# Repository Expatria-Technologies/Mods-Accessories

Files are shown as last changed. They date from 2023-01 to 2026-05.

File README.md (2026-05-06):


### Canadian-designed open source hardware. For everyone.

# Mods & Accessories
Here you will find 3D printed enclosures, mounts, buttons, and community submitted mods for the Expatria hardware.

## Submitting Mods
When submitting a PR for a mod, please update the table in the relevant section with the following:
- Your desired creator name
- A mod title & link to your sub-folder
- A description of what you have created
- Compatibility with the various Expatria hardware, if the table within the section includes space for this. Use `:heavy_check_mark:` for :heavy_check_mark:, `:x:` for :x: and `:grey_question:` for :grey_question:

Within the sub-folder for your mod, please include a brief README with any details you think are essential or helpful for use or assembly. 

## Jog2K

| Creator | Mod Title | Description | 
| --- | --- | --- |
| Expatria | [Jog2k Deluxe](./Expatria/Jog2K_Deluxe) | Jog2K Deluxe Enclosure |
| Expatria | [Jog2k Base](./Expatria/Jog2K_Base) | Jog2K Base Enclosure |
| Logan | [FDM Buttons](./Community_Submissions/FDM_Buttons) | FDM Buttons for Jog2K Deluxe Enclosure |
| RR |  [High-Vis Buttons](./Community_Submissions/Simplified_High_Vis_Buttons) | Simplified High Vis Buttons for Jog2K Deluxe Enclosure |

## Flexi-HAL

| Creator | Mod Title | Description | 
| --- | --- | --- |
| Expatria | [Flexi-HAL DIN Mount](./Expatria/Flexi-HAL_DIN_Mount) | Flexi-HAL DIN Mount |
| TAKUYA | [Flexi-HAL + PI DIN Mount](./Community_Submissions/FLEXI_HAL_PI_DIN_RAIL_MOUNT) | Flexi-HAL + PI DIN Mount |

## HAL2K

| Creator | Mod Title | Description |  HAL2K EST | HAL2K OG|
| --- | --- | --- | --- | --- |
| Logan | [GH2K PCB Mounting Plate](./Community_Submissions/GH2K_PCB_Mounting_Plate) | Mounting Plate for HAL2K | :heavy_check_mark: | :heavy_check_mark: |

## PicoBOB

| Creator | Mod Title | Description | 
| --- | --- | --- |
| miniwini | [PicoBOB Case](./Community_Submissions/PicoBOB_Case) | Case for PicoBOB |

## Limit Breakout

| Creator | Mod Title | Description | 
| --- | --- | --- |
| Expatria | [Limit PCB Case](./Expatria/Limit_PCB_Case) | Limit Breakout Case |
| miniwini | [Limit_PCB_Enclosure](./Community_Submissions/Limit_PCB_Enclosure) | Enclosure for Limit Switch PCB |

## Switch Breakout

| Creator | Mod Title | Description | 
| --- | --- | --- |
| Logan | [Button PCB Case](./Community_Submissions/Button_PCB_Case) | Button PCB Case |

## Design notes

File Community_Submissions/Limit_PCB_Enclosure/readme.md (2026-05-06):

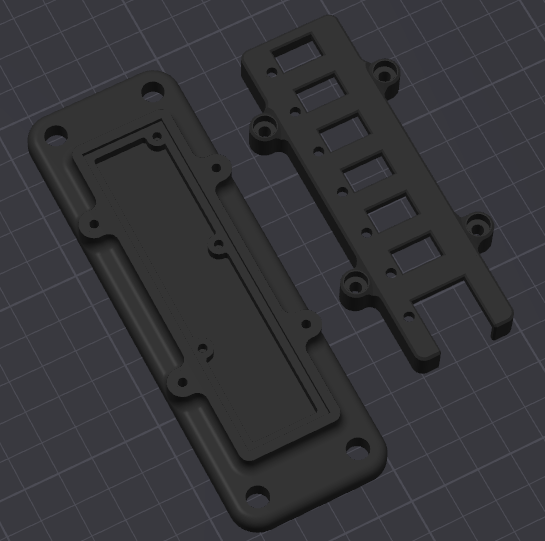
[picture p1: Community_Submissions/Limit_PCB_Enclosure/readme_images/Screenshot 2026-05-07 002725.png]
Screenshot of modified Expatria Limit PCB enclosure front view
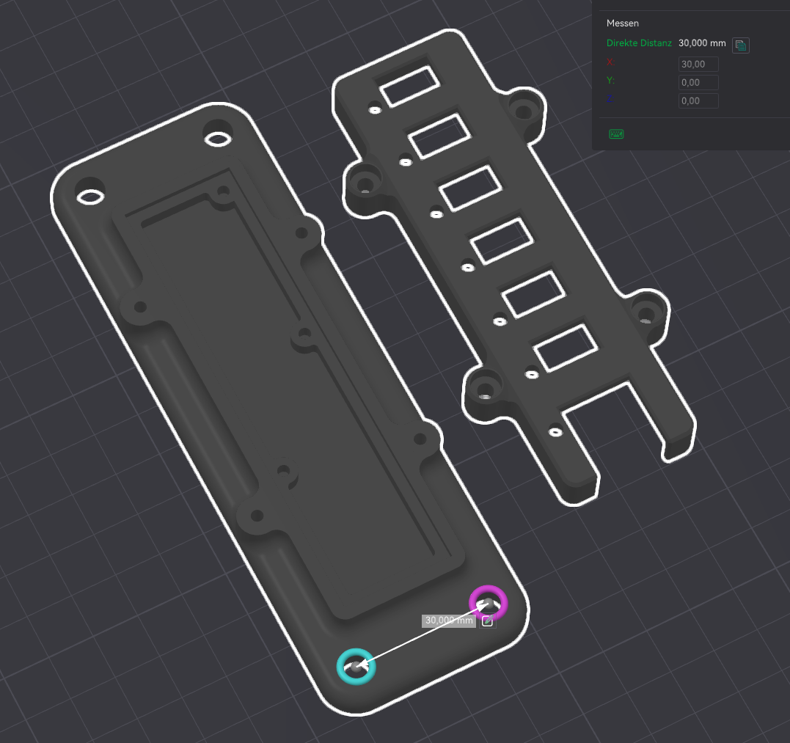
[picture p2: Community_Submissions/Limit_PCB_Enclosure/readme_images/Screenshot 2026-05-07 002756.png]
Screenshot of modified Expatria Limit PCB enclosure rear mounting holes
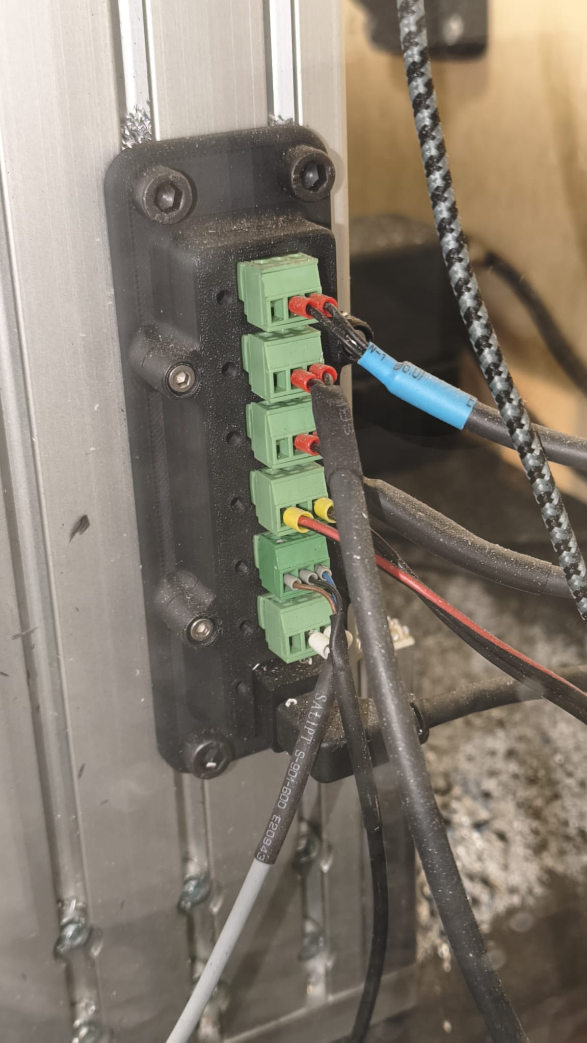
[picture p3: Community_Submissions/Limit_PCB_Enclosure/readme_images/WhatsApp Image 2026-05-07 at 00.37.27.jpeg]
Mounted Expatria Limit PCB enclosure on aluminium extrusion profile
<h2>Expatria Limit PCB Enclosure  </a>  – 60 mm Extrusion Mount</h2><p>  A modified version of the <strong><a href="https://github.com/mintracer/Mods-Accessories/tree/main/Expatria/Limit_PCB_Case" target="_blank">    Expatria Limit PCB Enclosure  </a></strong>,  adapted for mounting directly to a <strong>60 mm aluminium extrusion profile</strong>.</p><ul>  <li>Designed for 60 mm extrusion profiles</li>  <li>30 mm slot distance</li>  <li>Mounting holes sized for M6 screws</li>  <li>Clean and secure PCB enclosure mounting</li></ul><br><br><br><br><br>

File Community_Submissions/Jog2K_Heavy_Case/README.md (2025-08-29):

# Jog2k Heavy Industry Case

This is a case for the Jog2k with large, ergonomic grips and provisions for use of a longer cable.

**Warning**: This mod requires soldering custom cables, and possibly modifying SMT components on the Jog2k PCBs. As always, you are responsible for wiring things correctly to avoid possible damage to your hardware!

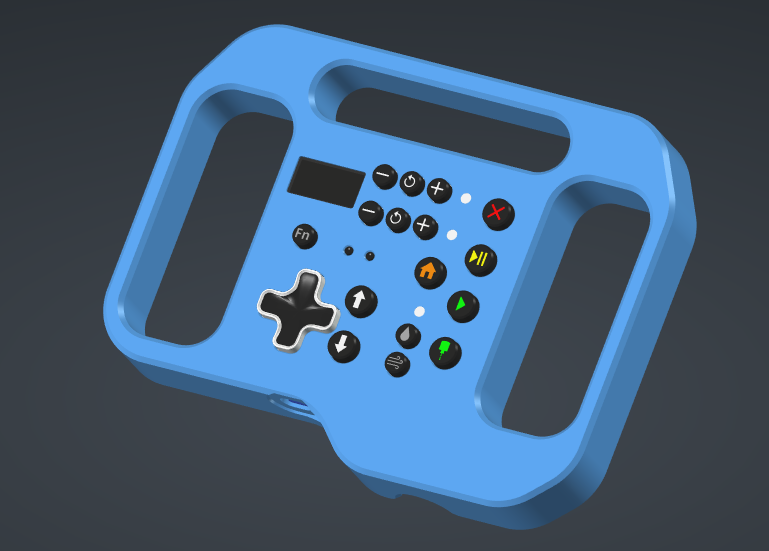
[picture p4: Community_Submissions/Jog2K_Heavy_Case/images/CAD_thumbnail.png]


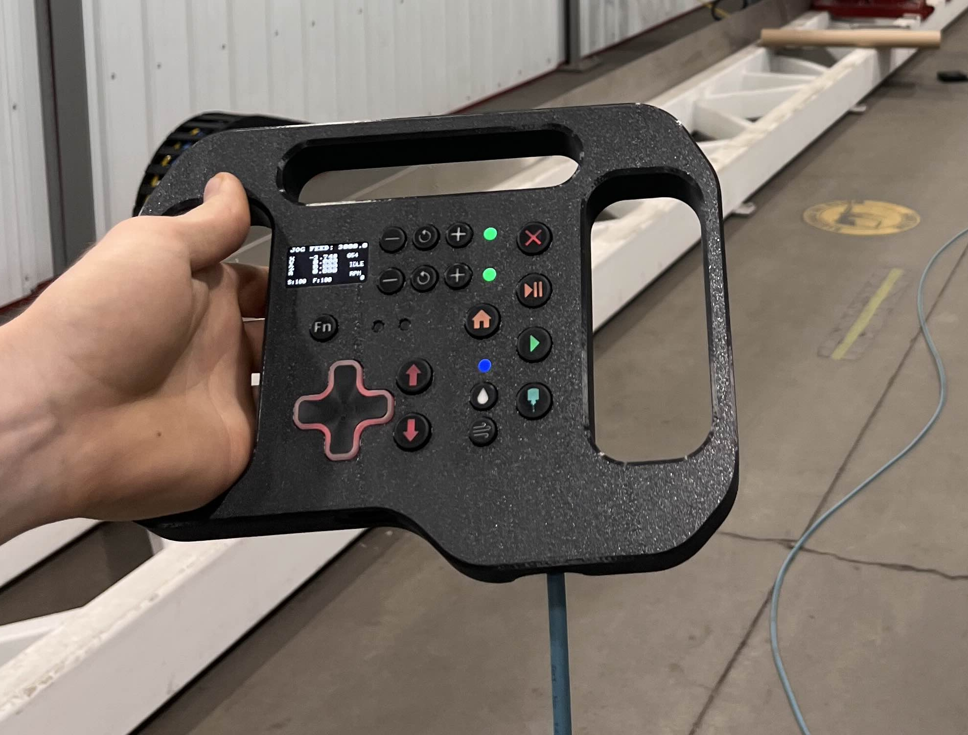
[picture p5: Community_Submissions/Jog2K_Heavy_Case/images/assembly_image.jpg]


## Bill of materials

- Jog2k [PCB](https://expatria.myshopify.com/products/jog2k-keypad-pendant-pcba) and [Buttons](https://expatria.myshopify.com/products/flexihal-encoder-breakout-pcba-copy).
- 3D printed [front](./CAD/case_front.stl) and [back](./CAD/case_back.stl) case halves.
- 4x M3 threaded inserts, E.G.: [These ones](https://cnckitchen.store/products/heat-set-insert-m2-x-3-100-pieces) from CNC kitchen.
- 4x M3 socket head cap screws, 10mm long.
- industrial Ethernet cable with at least on M12 end. E.G.: [This one](https://www.digikey.com/short/9mrhdw5j). This is a standard part, also available from many sellers on Amazon or the like.
- M12 bulkhead connector to match your cable. E.G.: [This one](https://www.digikey.ca/short/vz40fct9) or something equivalent.

Note that M12 connectors are available in **A-coded**, **X-coded**, and other variants. Any of them will work if at least **6** pins are available, as long as you purchase a matching cable and bulkhead connector.

## Assembly notes

- Print the enclosure parts and install the threaded inserts.
- Cut an existing right angle USB cable in half, and splice it in between the bulkhead connector, Ethernet cable, and Jog2k interface breakout PCBs. Carefully match each of the following 6 signals at either end of the cable:
  - +5V
  - GND
  - KPSTR (key press trigger)
  - HALT
  - SDA (Data)
  - SCL (clock)
- Consider using some kapton tape to manage the USB wires during final assembly of the case.

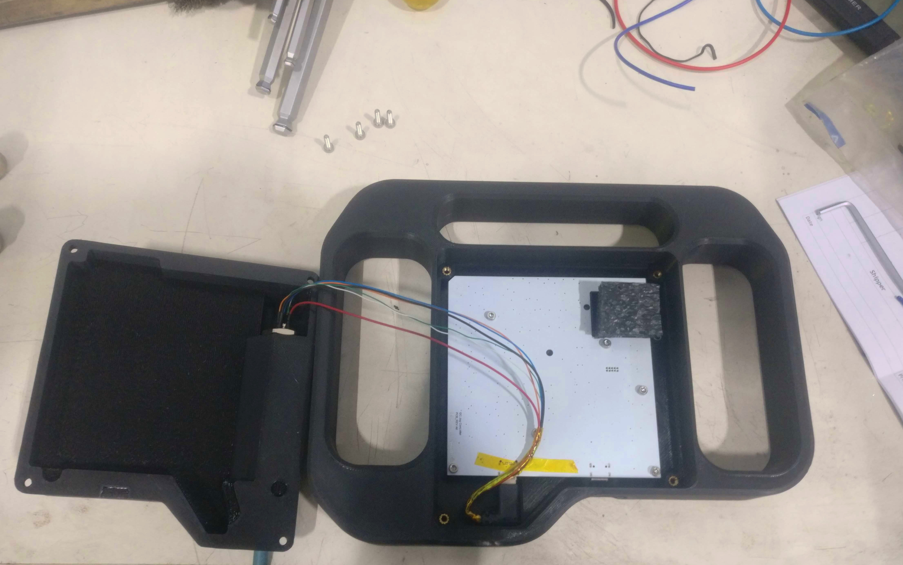
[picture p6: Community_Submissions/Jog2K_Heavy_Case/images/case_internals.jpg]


**Note**: Depending on the length of cable used, the I2C bus extenders on the Jog2k main and breakout PCBs may need to have their pull-up resistor adjusted. Refer to [this data sheet for the P82B715 bus extender chip](https://www.nxp.com/docs/en/data-sheet/P82B715.pdf).

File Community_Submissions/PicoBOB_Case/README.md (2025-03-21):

This is a Case for the PicoBOB

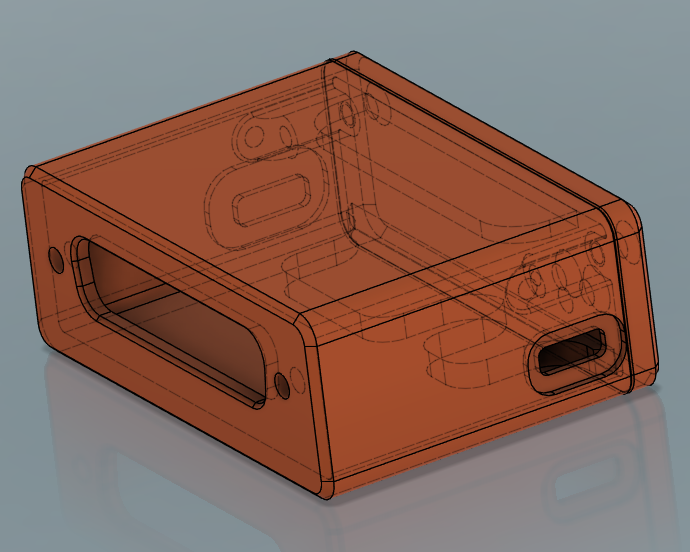
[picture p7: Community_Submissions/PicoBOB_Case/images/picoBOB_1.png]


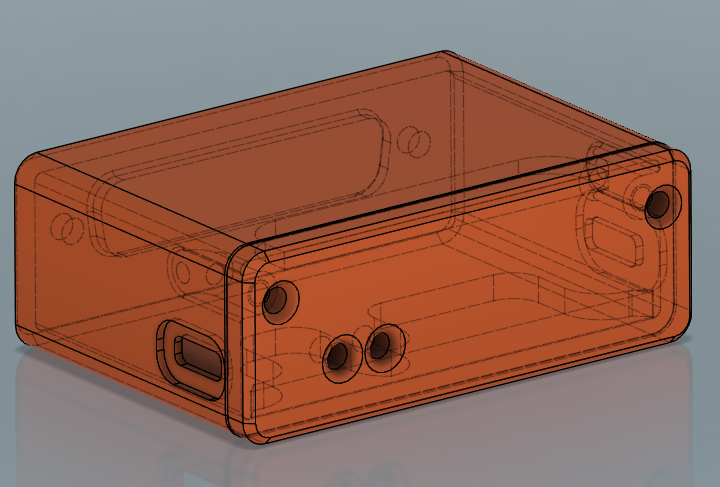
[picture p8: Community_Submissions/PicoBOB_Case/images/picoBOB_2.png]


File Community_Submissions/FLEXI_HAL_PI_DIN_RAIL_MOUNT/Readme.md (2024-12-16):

Remix of the already existing Flexi-Hal DIN rail Mount to include the pi.
Includes printed 11mm spacers between the FLexi_Hal and the Pi. 

BOM:
* 7x M3x8 BHCS
* 4x M2x18 SHCS or BHCS.

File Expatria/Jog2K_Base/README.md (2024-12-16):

# Jog2K A5 (earlier) I2C Jog Controller for GRBLHAL2000

These mechanicals are currently only set up for A5 and prior revisions.  They will not work well with the A6 slim PCBA.

This is the original enclosure for Jog2k, which can be printed completely via FDM/FFF. This version of the enclosure is simple to print, and provides all of the same core functionality as the Deluxe version, minus the labels. Buttons are printed in clear PETG.

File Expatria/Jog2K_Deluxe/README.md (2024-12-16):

# Jog2k Deluxe Enclosure

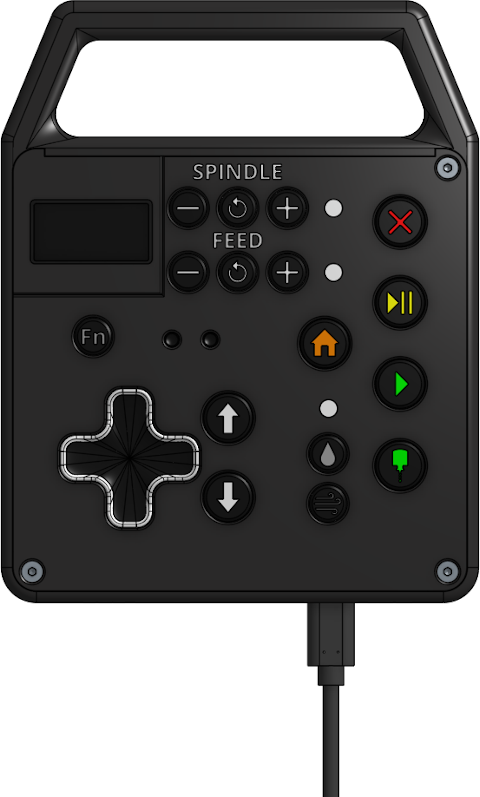
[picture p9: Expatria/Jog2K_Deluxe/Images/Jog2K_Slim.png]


## Variants
There are currently three variants of the Jog2K Deluxe, which support slight hardware differences. 
- 'Slim' supports revision A6 (two Type-C connectors), with a 1.3" OLED connected via a short cable.  This is the latest chip-down PCBA from Expatria, and what is shipped from the Expatria shop.
- '1.3in' supports all revisions up to and including A5, with a 1.3" OLED connected via a short cable
- '0.96in' supports all revisions up to and including A5, with a 0.96" OLED connected directly to the PCB via header pins

The differences are all in the enclosure components; the filenames within the Enclosure directory begin with the variant they are suitable for. The same buttons are used for all variants.

The majority of the following instructions are focused on the Slim variant, which is what is currently being shipped from the Expatria shop. The legacy A5 and prior revisions are similar, but do not feature the removable display insert. The assembly section includes notes intended to clarify which variant they apply to.

## Buttons
Buttons are designed for MSLA printing, and are assembled from 2 parts. The 'lightpipe' or 'core', and the 'cover'. Cores should be printed in white, lightpipes in translucent, and covers in black. There is a small amount of clearance designed in to the parts to allow for slight differences in resin tuning. Button pieces can be glued together with a small amount of CA glue if needed. 

In addition to the buttons contained here, there are several sets of community contributed mods for FDM/FFF printed buttons. They can be found in the table in the [top-level README](https://github.com/Expatria-Technologies/Mods-Accessories). 

## Enclosure
The enclosure is designed to be FDM/FFF printed with a standard 0.4mm nozzle in PLA. Print tolerances are somewhat critical here to avoid excess rotational slop in the buttons; ensure your extrusion multiplier is well tuned for your filament. Materials other than PLA may require compensation for shrinkage. 

The top cover prints best with a single perimeter on the bottom layer; the text gets a bit difficult otherwise, particularly on the A5 and prior enclosures, which have smaller text. There is a checkbox for this in SuperSlicer: Under Quality --> Only One Perimeter check the 'On First Layer' box. 

The Slim variant splits the display section of the cover into a separate insert. An insert for 1.3" displays is provided that should be compatible with most displays available via AliExpress, and a blank insert is provided if you wish to customize the the enclosure for a different display.

There is a recess in the rear of the 0.96" enclosure for a window in the same shape as the base enclosure. It can be cut from acrylic and glued in from the rear, with the lip hiding any glue residue. A window is not required for the 1.3" variant, which mounts the display in a recess in the front panel.

Holes for the fasteners that secure the lid are designed to accept heatset inserts of the Voron typical variety. The board is secured with self-tapping screws, as it is likely to be removed less often and it allows for more wiggle room for print tolerances.

## Enclosure Parts to Print

#### Slim (Rev A6):
- 1x Slim - Bottom Enclosure.stl
- 1x Slim - Top Cover.stl
- 1x Slim - 1.3in Display Insert.stl

#### Rev A5 and Prior with 1.3" OLED:
- 1x 1.3in - Bottom Enclosure.stl
- 1x 1.3in - Top Cover.stl
- 1x 1.3in - Display Retainer.stl

#### Rev A5 and Prior with 0.96" OLED:
- 1x 0.96in - Bottom Enclosure.stl
- 1x 0.96in - Top Cover.stl

## Hardware Required

#### Slim (Rev A6):
- 3x - M3 heatset inserts - 3 x 3 x 5mm - https://www.aliexpress.com/item/1005003286574326.html
- 3x - M3 x 14mm flat head screws  - https://www.aliexpress.com/item/32965177647.html
- 7x - M2.6 x 8mm self tapping screws - https://www.aliexpress.com/item/32970730241.html

#### Rev A5 and Prior:
- 4x - M3 heatset inserts - 3 x 4 x 5mm - https://www.aliexpress.com/item/1005003286574326.html
- 4x - M3 x 16mm flat head screws  - https://www.aliexpress.com/item/32965177647.html
- 7x - M2.6 x 8mm self tapping screws - https://www.aliexpress.com/item/32970730241.html

## Assembly
- Trim/deburr/clean up printed enclosure halves.
- Install heat set inserts into the bottom half of the enclosure.

- **Slim only:** Install display in display insert with hot glue or epoxy, taking care to center the display in the opening. There is a fair bit of tolerance in the recess to allow for slight differences in PCBs and the attachment of the glass OLED to the OLED PCB:

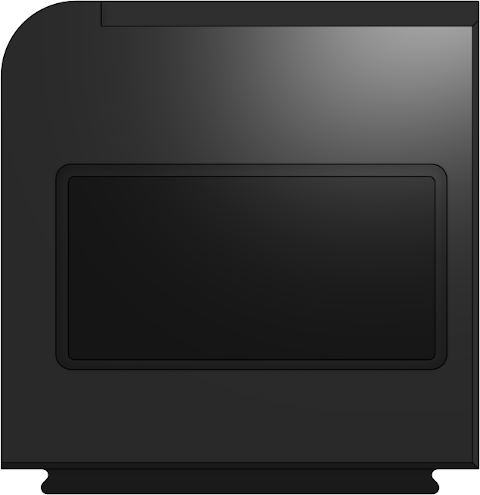
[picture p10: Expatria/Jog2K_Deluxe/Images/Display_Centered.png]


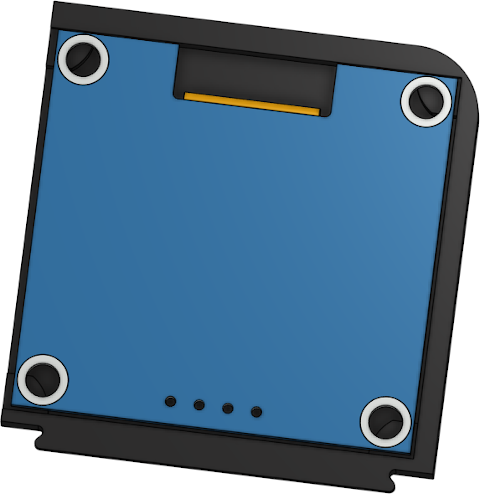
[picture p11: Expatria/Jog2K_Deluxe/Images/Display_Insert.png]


- Clip display insert into top cover, and insert lightpipes. Lightpipes are a fairly tight press fit. Some trimming of the holes may be required if the fit is too tight. A tapered reamer as linked in the Notes section is ideal, or step drill with a 4mm step will also work:

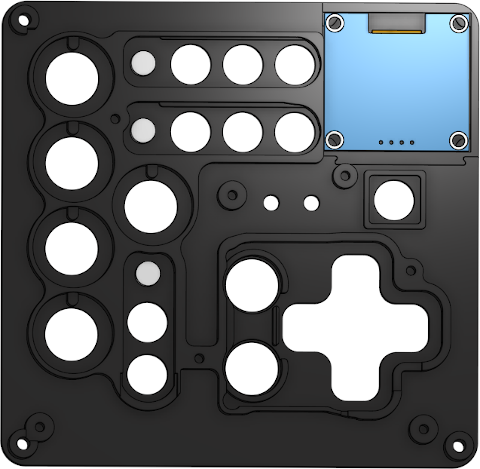
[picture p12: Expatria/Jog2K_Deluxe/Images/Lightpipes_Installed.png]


- Insert buttons in all button holes:

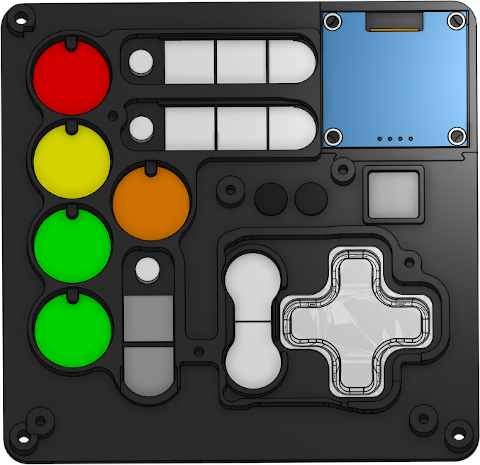
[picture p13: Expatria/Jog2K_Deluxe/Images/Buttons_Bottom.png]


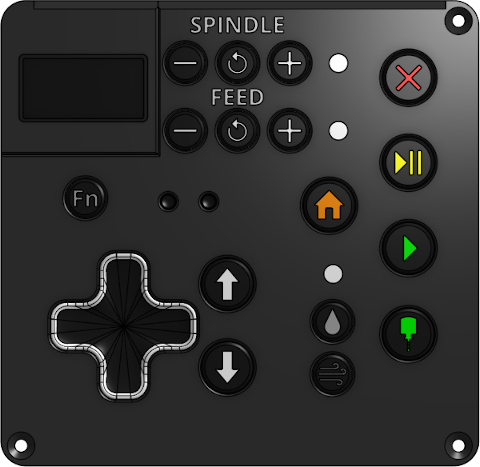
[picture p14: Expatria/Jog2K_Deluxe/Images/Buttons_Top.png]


- **Rev A5 and prior only:** Align the screen and either heat-stake the plastic mounting pins or use the support bracket.
## DO NOT SOLDER THE SCREEN DIRECTLY TO THE PCB
- **1.3" display versions, including Slim:** Connect screen to PCB via short wires or cable.

- Align PCB with holes/captures
- Insert M2.6 x 8mm self tapping screws where shown and tighten (display cable not shown):

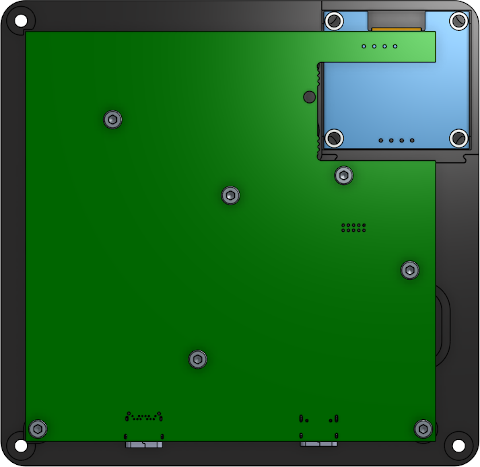
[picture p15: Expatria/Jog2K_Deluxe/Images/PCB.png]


- Flip cover over and ensure all buttons are operational. If any are stuck, loosen screws on PCB and adjust alignment slightly.
- Insert assembled top cover into back enclosure. The slim variant has a lip along the top that captures the edge of the top cover, keeping the display insert in place. The top cover must first be inserted under this lip at a slight angle and pivots down into place: 

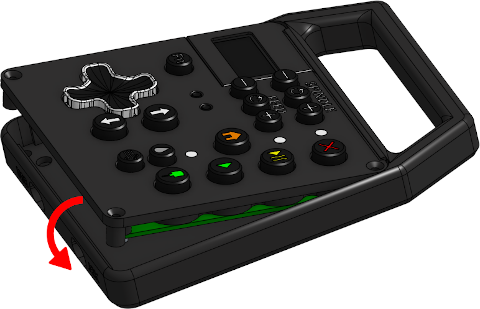
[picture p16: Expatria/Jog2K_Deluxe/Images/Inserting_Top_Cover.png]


- Insert M3 x 14mm **(slim)** or M3 x 16mm **(A5 and prior)** flat head screws and tighten. 

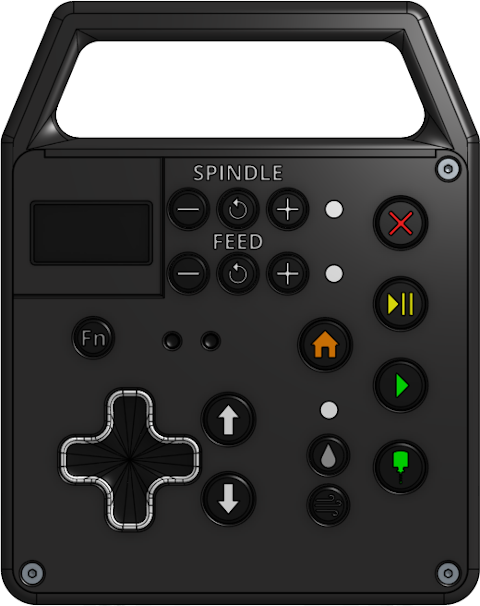
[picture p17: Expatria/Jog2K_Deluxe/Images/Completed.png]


## Notes
- Pretty much any resin type will work. Success has been had with Elegoo Standard, Siraya Tech Fast, and Eryone ABS-like.
The resin buttons may warp slightly at the base as the resin shrinks. The clearances of the cover have been designed such that any warping here shouldn't cause a problem.
- Print the black resin parts last. The resin will shrink in the first day or so after printing, and it will be easier to get them on if the other parts have shrunk a bit first. If print settings are well tuned, the black covers will fit tightly enough after shrinking that they will stay put on their own. 
- Likewise, the buttons may fit too tightly in the enclosure right after printing. They will loosen up a bit after a day or so of resting, when they are at final dimension.
- A tapered reamer of the type typically used for RC car bodyshells is an ideal tool for cleaning up first layer 'squish' in round holes or fine tuning the lightpipe holes. - https://www.aliexpress.com/item/1005003460682946.html They're usually available on Amazon for about $10 too.
- The bolt pattern on the low-cost 1.3 inch OLED screens is not consistent across vendors.  Jog2K Slim PCBA from Expatria have used a 1.3 inch OLED from this Aliexpress listing: https://www.aliexpress.com/item/32839718675.html **These displays are only compatible with the Slim enclosure components.**

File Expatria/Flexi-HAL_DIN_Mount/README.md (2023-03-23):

DIN mount from MikeM

2x clips per mount, 8x M3x8 screws - either self tapping or machine screws rammed into the plastic will work.

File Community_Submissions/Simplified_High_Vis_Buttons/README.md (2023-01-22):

When I first assembled my Jog2K, I hard some trouble assembling the buttons. And they didn't look great. I decided to modify the two part buttons that were black and white in order to simplify the assembly process and provide greater contrast. The existing versions were modified to produce a single part button with icons that are wide enough to color using a black Ultra Fine Point Sharpie for added contrast. I later decided that the same process would work on the top case cover to improve legibility of the "Spindle Override" and "Feed Override" text. I didn't modify the cover, just printed it in a light color. This part of the mod is a bit difficult since the lettering is only about .7mm wide and the sharpie is about 1mm wide, but it will squeeze in if you take your time.

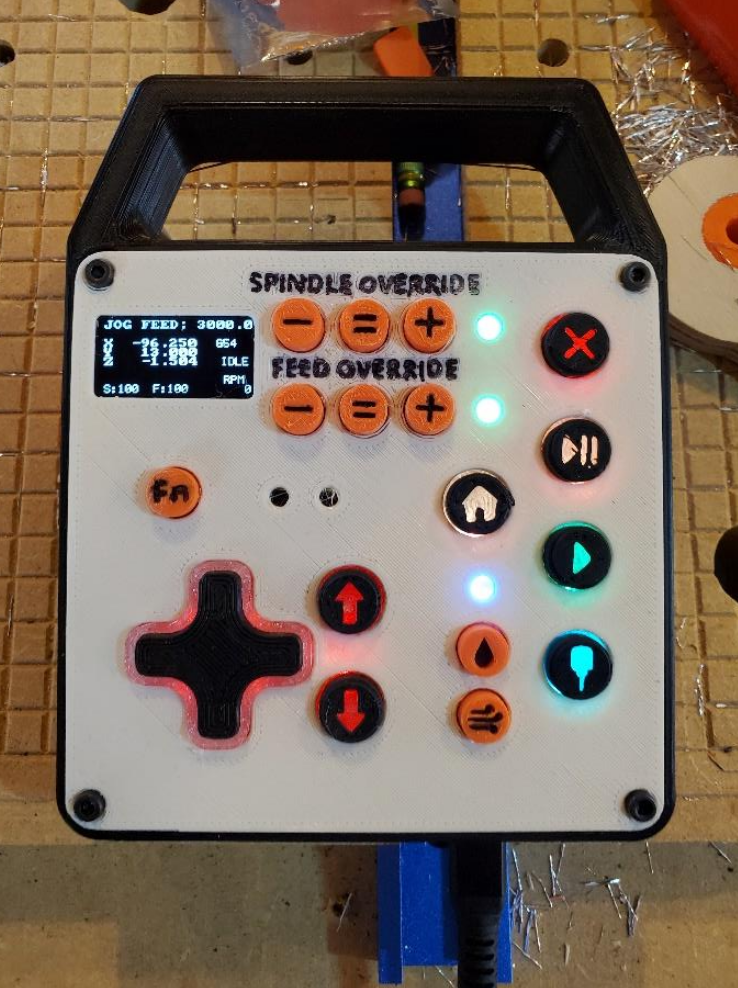
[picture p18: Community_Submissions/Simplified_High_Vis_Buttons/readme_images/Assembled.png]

 
Instructions:
1)	Print the case top in white (or some other light color). Use a dark Ultra Fine Point Sharpie to color in the text. For extra credit, you could modify the text to be a bit wider which would make the coloring easier.
2)	You no longer need to print any of the white buttons in the Deluxe version's White [FDM Button](../FDM_Buttons) folder. In the black [FDM Button](../FDM_Buttons) folder, you also don't need to print the black keycaps for the Flood Button Cover, the Fn Button Cover, the Mist Button Cover, the two Minus Button Covers, the two Plus Button Covers, and the two Reset Button Covers.
3)	Print and use the 9 button covers in this folder. Use a dark Ultra Fine Point Sharpie to color in the icons.

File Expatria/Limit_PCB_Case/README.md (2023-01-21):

# Limit Breakout Case

This enclosure can be used two ways. The bottom half can be used as a mounting plate on its own:

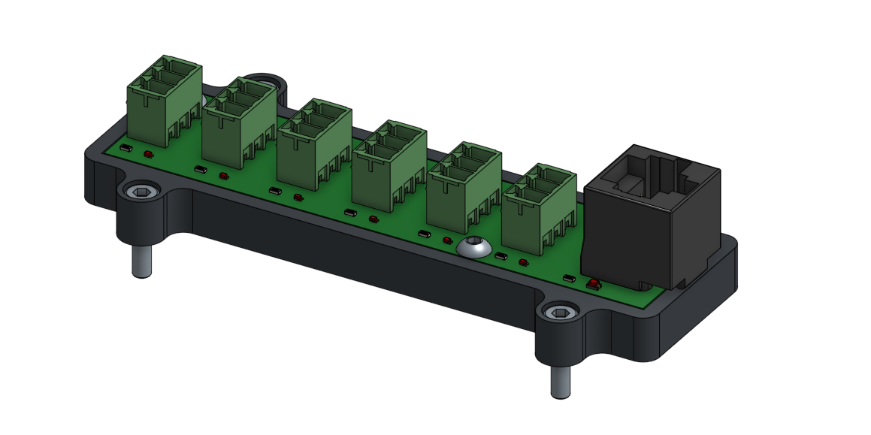
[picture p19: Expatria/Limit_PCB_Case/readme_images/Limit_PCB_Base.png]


Or the whole enclosure can be assembled, with the cover and lightpipes: 

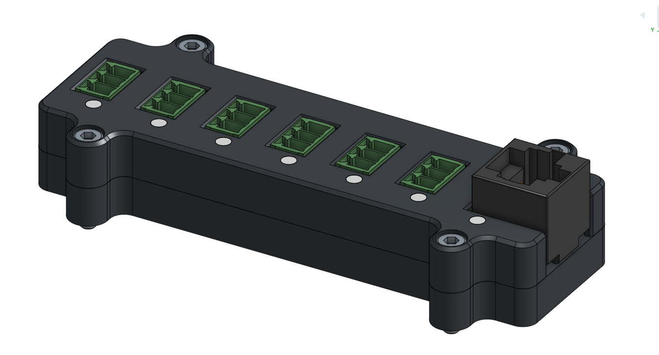
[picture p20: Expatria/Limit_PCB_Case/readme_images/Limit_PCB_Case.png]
 

The lightpipes can be omitted if desired, with the LEDs shining through the holes. 

All hardware is M3. If using the cover, the light baffles in the lid are sufficient to retain the PCB without PCB screws, however, the two on the side opposite the LEDS can be installed if desired.

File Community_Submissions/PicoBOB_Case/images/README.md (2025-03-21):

This folder contains all Images relating to the PicoBOB Case

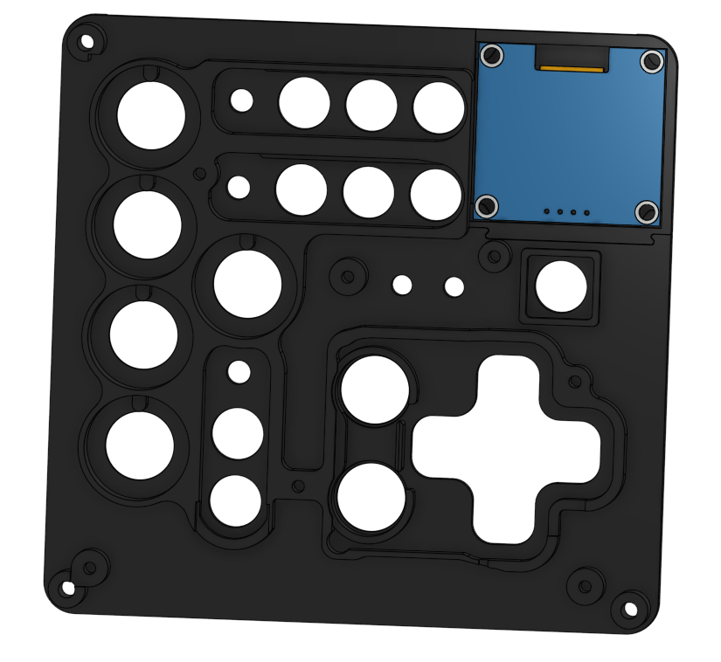
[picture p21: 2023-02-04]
Expatria/Jog2K_Deluxe/Images/Top_Cover.png

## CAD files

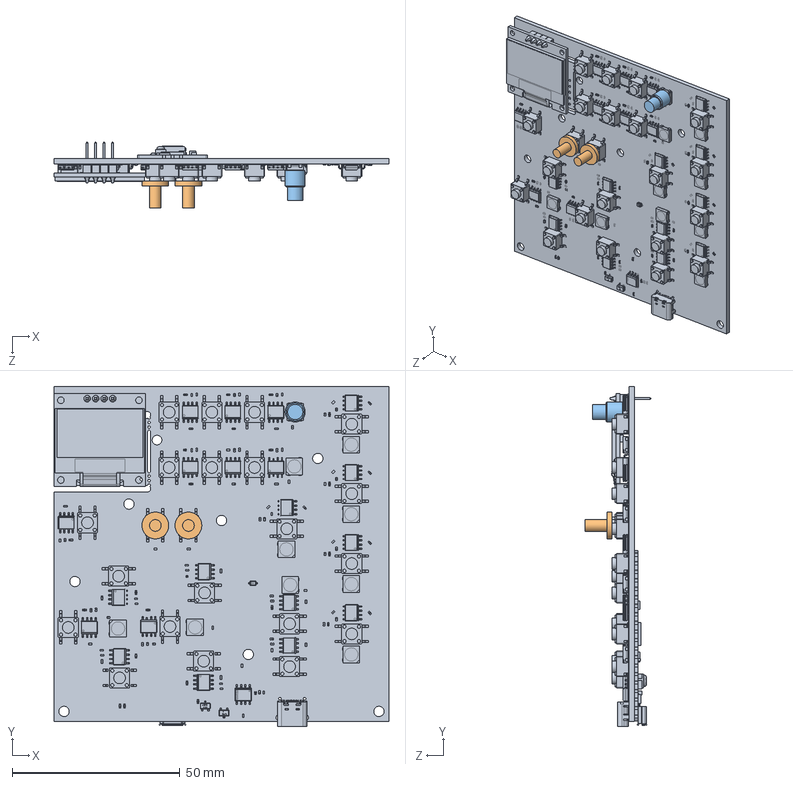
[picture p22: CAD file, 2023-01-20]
Expatria/Jog2K_Base/jog_box.SLDASM
100.0 x 101.5 x 19.7 mm
I2C_Jog_Controller_R4
4mm_button x 2
lightpipe

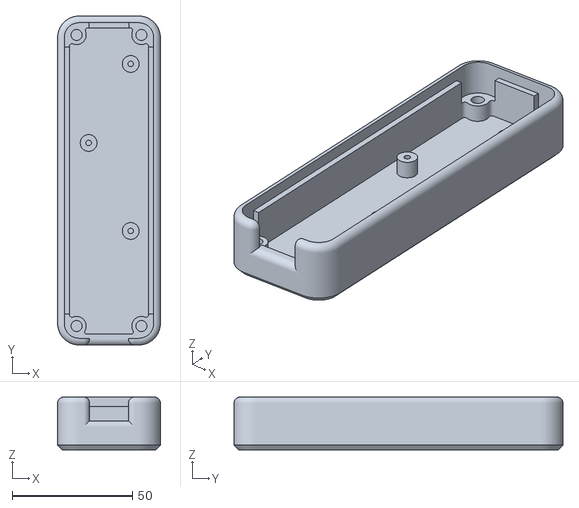
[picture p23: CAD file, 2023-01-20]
Community_Submissions/Button_PCB_Case/Button PCB Case Bottom.stl
42.8 x 136.9 x 22.0

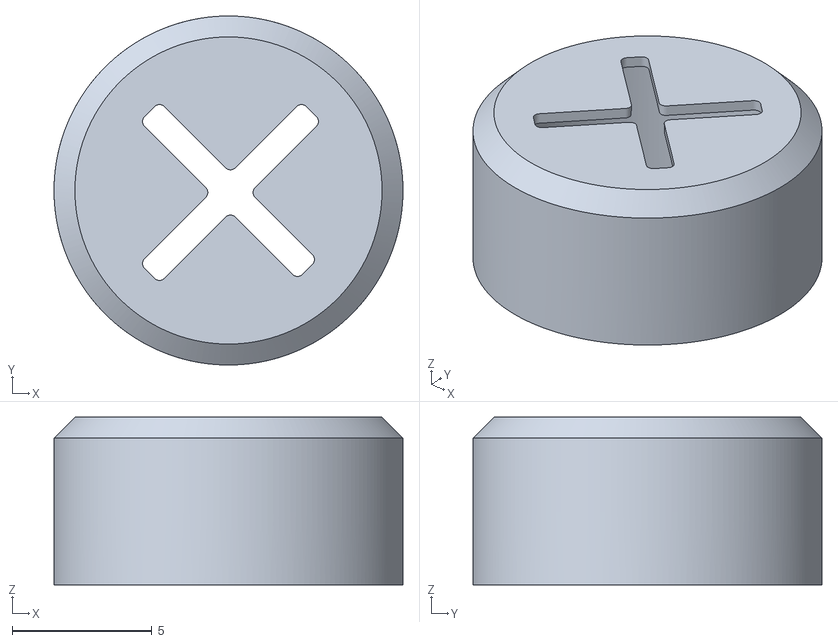
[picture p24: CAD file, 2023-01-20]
Community_Submissions/Button_PCB_Case/FDM Buttons/Black/Halt Button Cover.stl
12.5 x 12.5 x 6.00

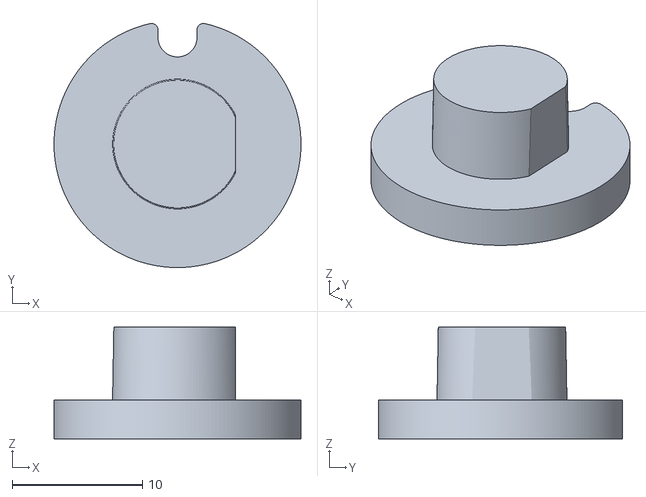
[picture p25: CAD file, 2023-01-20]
Community_Submissions/Button_PCB_Case/FDM Buttons/Translucent/Large Button Lightpipe 3x.stl
19.0 x 18.8 x 8.60

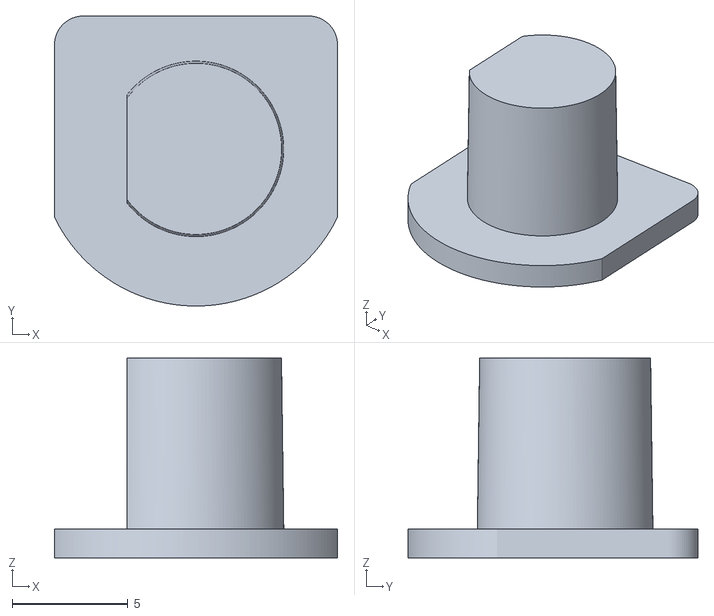
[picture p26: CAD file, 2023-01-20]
Community_Submissions/FDM_Buttons/White/White Button Core 3x.stl
12.2 x 12.5 x 8.65

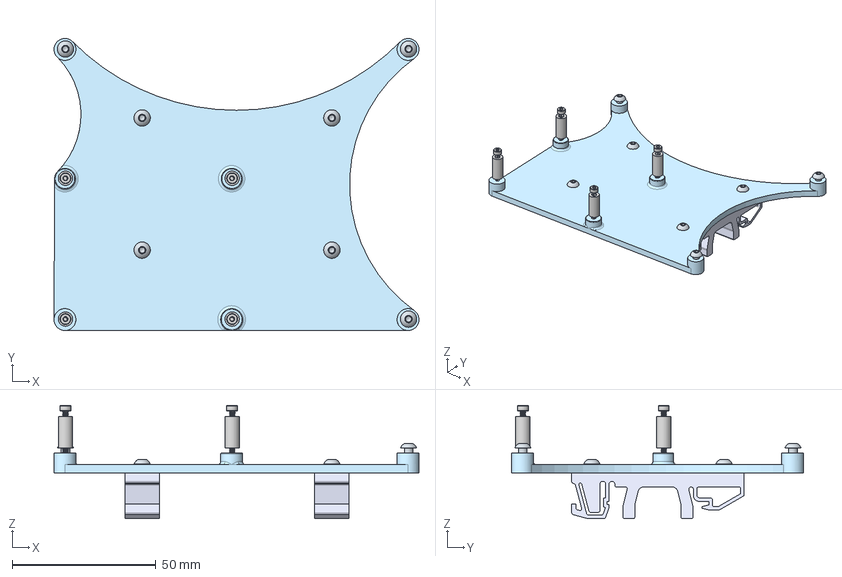
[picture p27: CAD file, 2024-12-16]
Community_Submissions/FLEXI_HAL_PI_DIN_RAIL_MOUNT/CAD/Flexi-HAL_PI_DIN_Mount.step
127.0 x 101.6 x 39.4 mm
DIN Clip x 2
Mount
Socket button head screw M3x0.5 x 8 x 7
M2x11 Spacer x 4
92290A850_Super-Corrosion-Resistant 316 Stainless Steel Socket Head S crew x 4

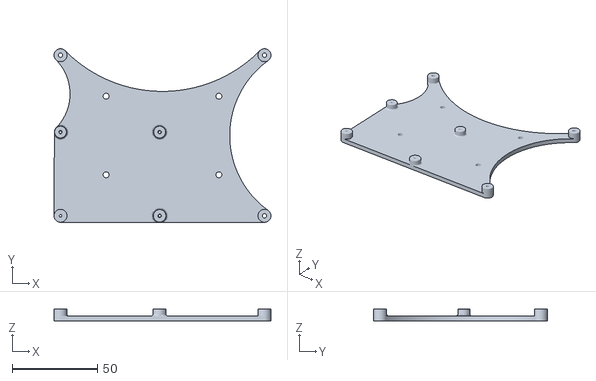
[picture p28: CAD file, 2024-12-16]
Community_Submissions/FLEXI_HAL_PI_DIN_RAIL_MOUNT/STL/Flexi-HAL_Mount_Plate.stl
127.0 x 101.6 x 7.00

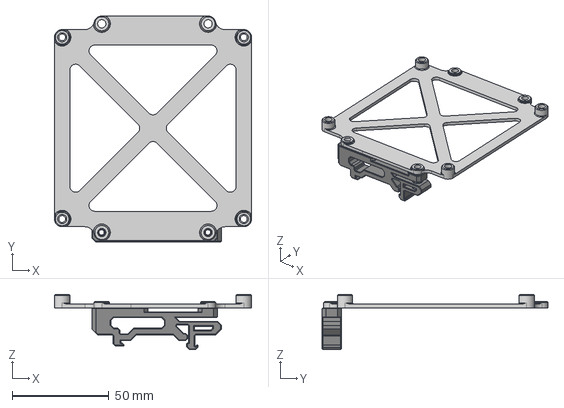
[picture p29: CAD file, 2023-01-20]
Community_Submissions/GH2K_PCB_Mounting_Plate/GH2K Din Mounting Plate v1.step
102.0 x 116.9 x 28.6 mm

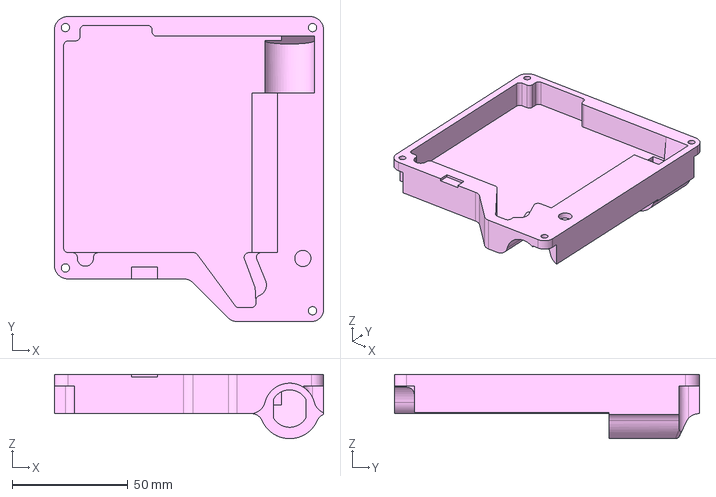
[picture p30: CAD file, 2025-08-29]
Community_Submissions/Jog2K_Heavy_Case/CAD/case_back.step
116.5 x 131.8 x 27.8 mm

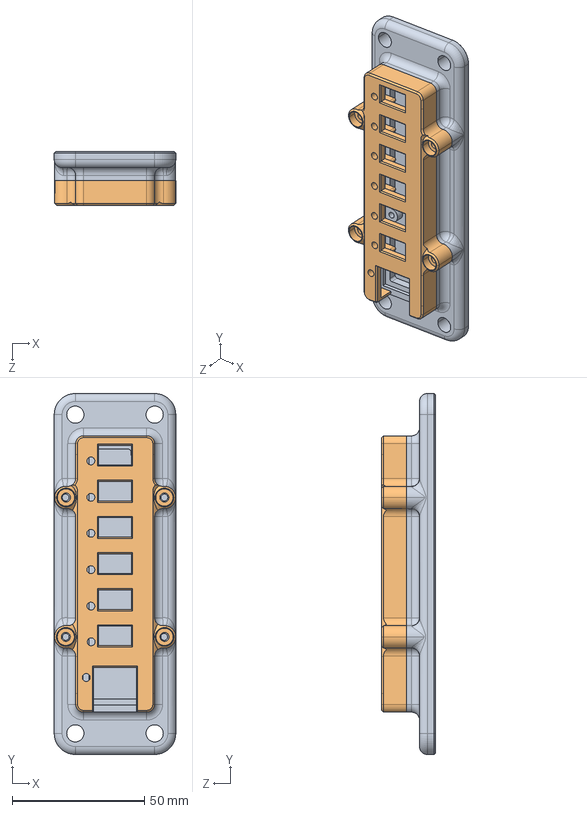
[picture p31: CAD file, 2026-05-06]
Community_Submissions/Limit_PCB_Enclosure/limit_breakout_case_item.STEP
46.0 x 136.5 x 20.3 mm
Limit Breakout Case_bottom.STEP_Standard
Limit Breakout Case.STEP_lid_Standard

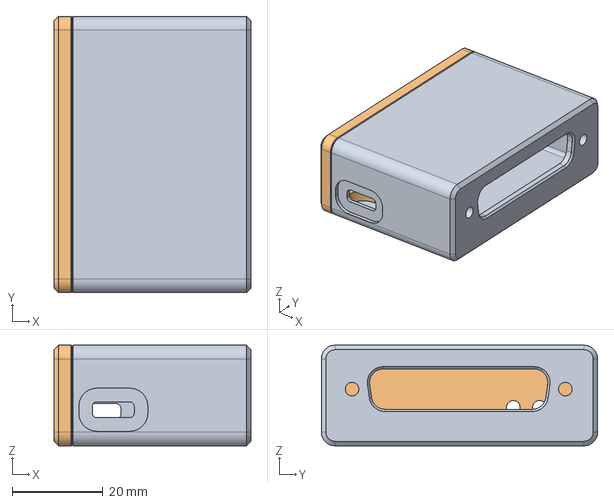
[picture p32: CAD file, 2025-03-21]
Community_Submissions/PicoBOB_Case/STEP/PicoBOB_Case_miniwini.step
43.5 x 61.0 x 22.2 mm

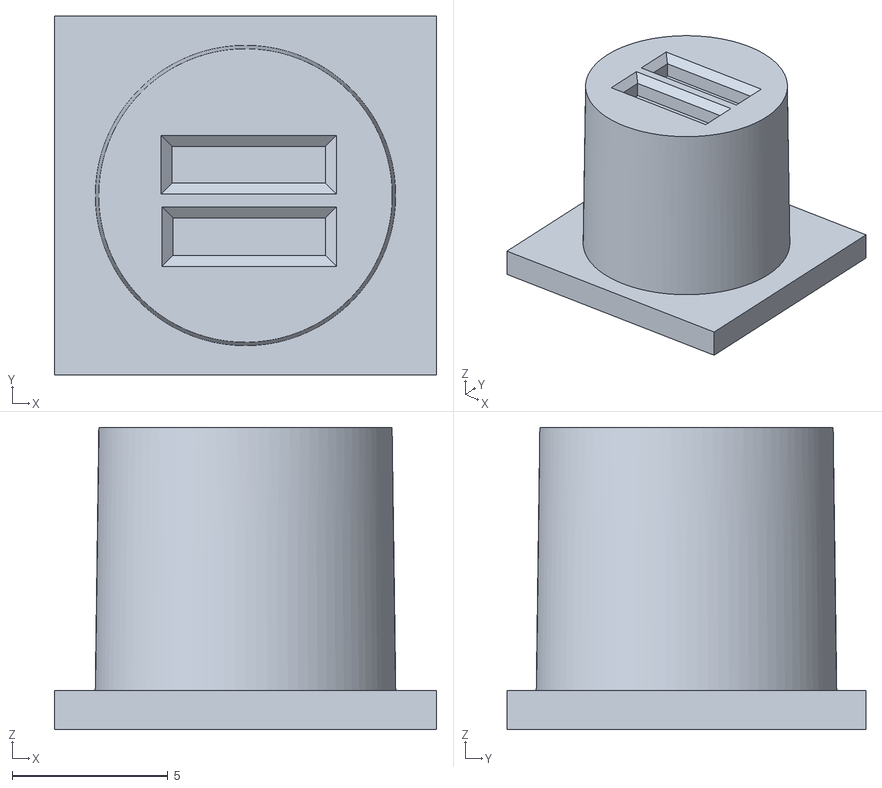
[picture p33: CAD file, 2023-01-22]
Community_Submissions/Simplified_High_Vis_Buttons/EqualOverrideX2.stl
12.2 x 11.5 x 9.69

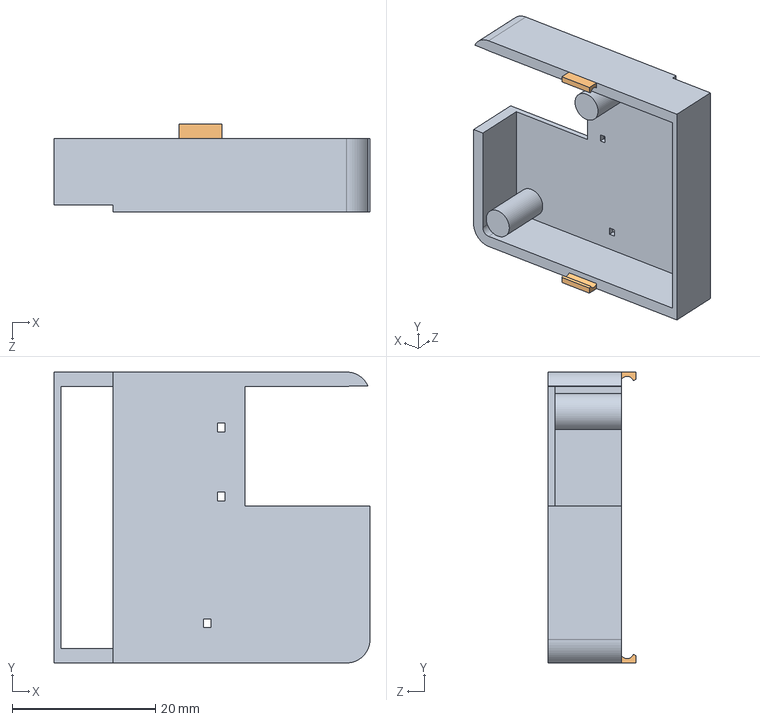
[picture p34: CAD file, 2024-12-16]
Expatria/Encoder_MK2_Case/encoderMK2_Enclosure_top.STEP
44.1 x 40.6 x 12.3 mm

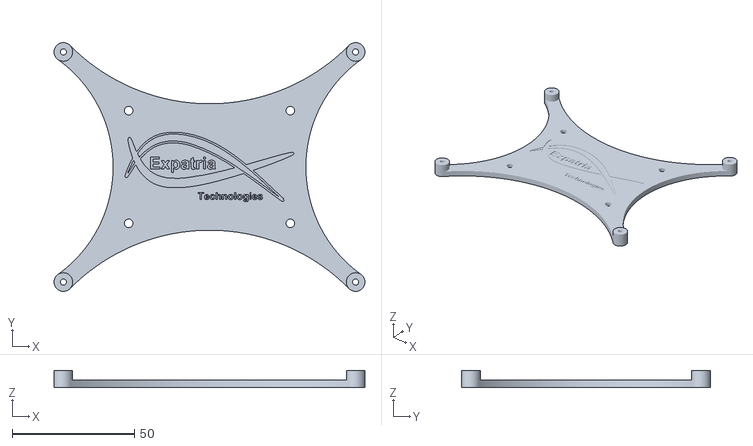
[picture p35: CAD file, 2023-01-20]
Expatria/Flexi-HAL_DIN_Mount/Flexi-HAL_Mount_Plate.stl
127.0 x 101.6 x 7.00

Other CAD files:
Expatria/Jog2K_Base/6mm_button.SLDPRT
Expatria/Jog2K_Deluxe/Buttons/Black/Start Button Cover.stl
Community_Submissions/Button_PCB_Case/Button Breakout Case v2.step
Community_Submissions/Button_PCB_Case/Button PCB Case Cover.stl
Community_Submissions/Button_PCB_Case/Button PCB Case v2.f3d
Community_Submissions/Button_PCB_Case/FDM Buttons/Black/Hold Button Cover.stl
Community_Submissions/Button_PCB_Case/FDM Buttons/Black/Start Button Cover.stl
Community_Submissions/FDM_Buttons/Black/D-Pad Upper.stl
Community_Submissions/FDM_Buttons/Black/Flood Button Cover.stl
Community_Submissions/FDM_Buttons/Black/Fn Button Cover.stl
Community_Submissions/FDM_Buttons/Black/Hold Button Cover.stl
Community_Submissions/FDM_Buttons/Black/Home Button Cover.stl
Community_Submissions/FDM_Buttons/Black/MicroUSBFiller.stl
Community_Submissions/FDM_Buttons/Black/Minus Button Cover 2X.stl
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

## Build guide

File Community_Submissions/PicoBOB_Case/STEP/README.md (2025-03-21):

This Folder contains the CAD STEP File of the PicoBOB Case

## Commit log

2023-01-20 Fix folder name (oops.)
    [DIN_Clip.stl, Flexi-HAL_Mount_Plate.stl]
2023-01-22 Increase clearance for USB-C connector
    [0.96in - Jog2k Deluxe Edition.step, 0.96in - Top Cover.stl, 1.3in and Slim - Top Cover.STEP]
2023-01-22 Import Simplified High Vis Buttons by RR
    [Coolant.stl, EqualOverrideX2.stl, FnButton.stl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]
2023-02-04 Update Slim enclosure to remove interferances with PCBA, split display section into insert, and fit most 1.3" displays. Rename and reorganize STLs. Update README.
    [0.96in - Jog2K Deluxe Edition.step, 0.96in - Jog2k Deluxe Edition.step, 1.3in - Display Retainer.stl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]
2023-02-19 Correct number of screws needed for Flexi-HAL DIN Mount in the README
2023-03-23 Fix missing text in 1.3in STEP, migrate enlarged text from slim for better printability.
    [1.3in - Top Cover.STL]
2024-10-30 Create FLEXI_HAL + PI DIN rail mount
2024-10-30 FIX Structure
    [DIN_Clip.stl, Flexi-HAL_Mount_Plate.stl, Flexi-HAL_PI_DIN_Mount.step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]
2024-12-14 FIX STL
    [Flexi-HAL_Mount_Plate.stl]
2024-12-16 Commit encoder MK2 case.
    [encoderMK2_Enclosure_bottom.STEP, encoderMK2_Enclosure_top.STEP]
2025-08-29 add jog2k heavy case
    [case_back.step, case_back.stl, case_front.step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]
